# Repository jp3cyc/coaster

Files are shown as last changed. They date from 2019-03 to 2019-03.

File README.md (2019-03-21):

# coaster
光る！コースタです。いざって時(e.g. 友達が遊びに来た、地震、台風の時とか)にはArduinoとしても活躍します。

# 用意するもの
## 部品
- チップLED 1608サイズ 12個
- チップ抵抗 270Ω 1608サイズ 12個
- チップ抵抗 10kΩ 1608サイズ 1個
- ATMEGA328P-AU 1個
- 基板実装型スイッチ 1個
- CR2032表面実装型ケース 1個
- CR2032 1個

## 道具
- AVR書き込み機　または Arduino UNO
- はんだごて
- はんだ
- リフロー炉（あれば楽）
- クリームはんだ（あれば楽）
- ピンセット（あれば便利）
- 顕微鏡（あれば便利）
- レーザ加工機（自宅にあると◎、ない場合はファボラボ or カインズに行く、カッターで頑張るのもあり）

# How to makke
1. プリント基板を注文する。Fusion PCB、PCBgogo、Elecrowとか。10枚$10＋送料です。coaster/circuit/garb/coaster-garbdata.zipを送るだけ
1. プリント基板が届くまでに部品を注文する。http://aki.prioris.jp/list/31d5aa3b-d171-41f0-a121-0a985a356ac1/ ワンクリックですべての部品があきづきカートに入ります。一個分の部品です。
1. コースタ基板を入れるためのケースを作ります。coaster-cutting.aiに入っているデータを誤自宅のレーザカッタで切断します。データはIllustrator形式ですが、みるだけならCoral Drawとかでもいけます。
1. はんだづけします。
1. AVRのFuseビットを変更します。lfuse:0xe2, hfuse:0xde, efuse:0x07（書き込めない場合はY1に8MHzの水晶、C1,C2に22pFのコンデンサをつけてみる）(firwareフォルダにコマンドが入っています）
1. プログラムを書き込みます。coaster-firmware/coaster-firmware.ino.with_bootloader.eightanaloginputs.hexを書き込みます。
1. ボタン電池を入れて、スイッチを入れるとつくはずです。つかなければ、電池残量、スイッチ、はんだ付けを見てみます。

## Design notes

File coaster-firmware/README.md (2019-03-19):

ヒューズ読み出し
avrdude -c usbasp -p m328p -U lfuse:r:con:h -U hfuse:r:con:h -U efuse:r:con:h

ヒューズ書き込み
avrdude -c usbasp -p m328p -U lfuse:w:0xe2:m -U hfuse:w:0xde:m -U efuse:w:0x07:m

bin書き込み
avrdude -c usbasp -p m328p -U flash:w:coaster-firmware.ino.with_bootloader.eightanaloginputs.hex

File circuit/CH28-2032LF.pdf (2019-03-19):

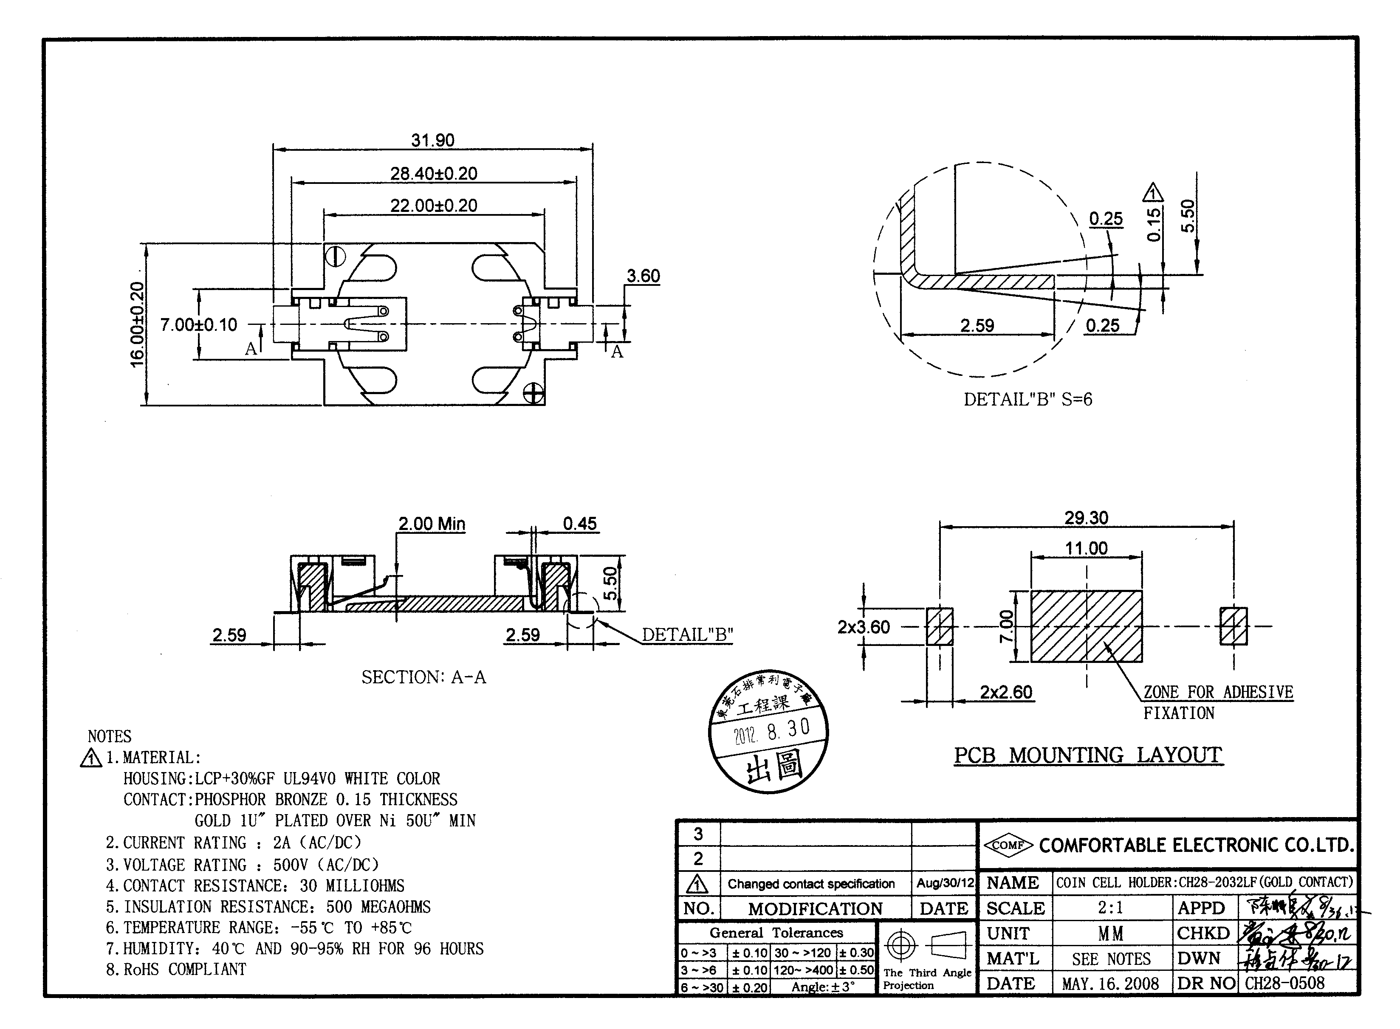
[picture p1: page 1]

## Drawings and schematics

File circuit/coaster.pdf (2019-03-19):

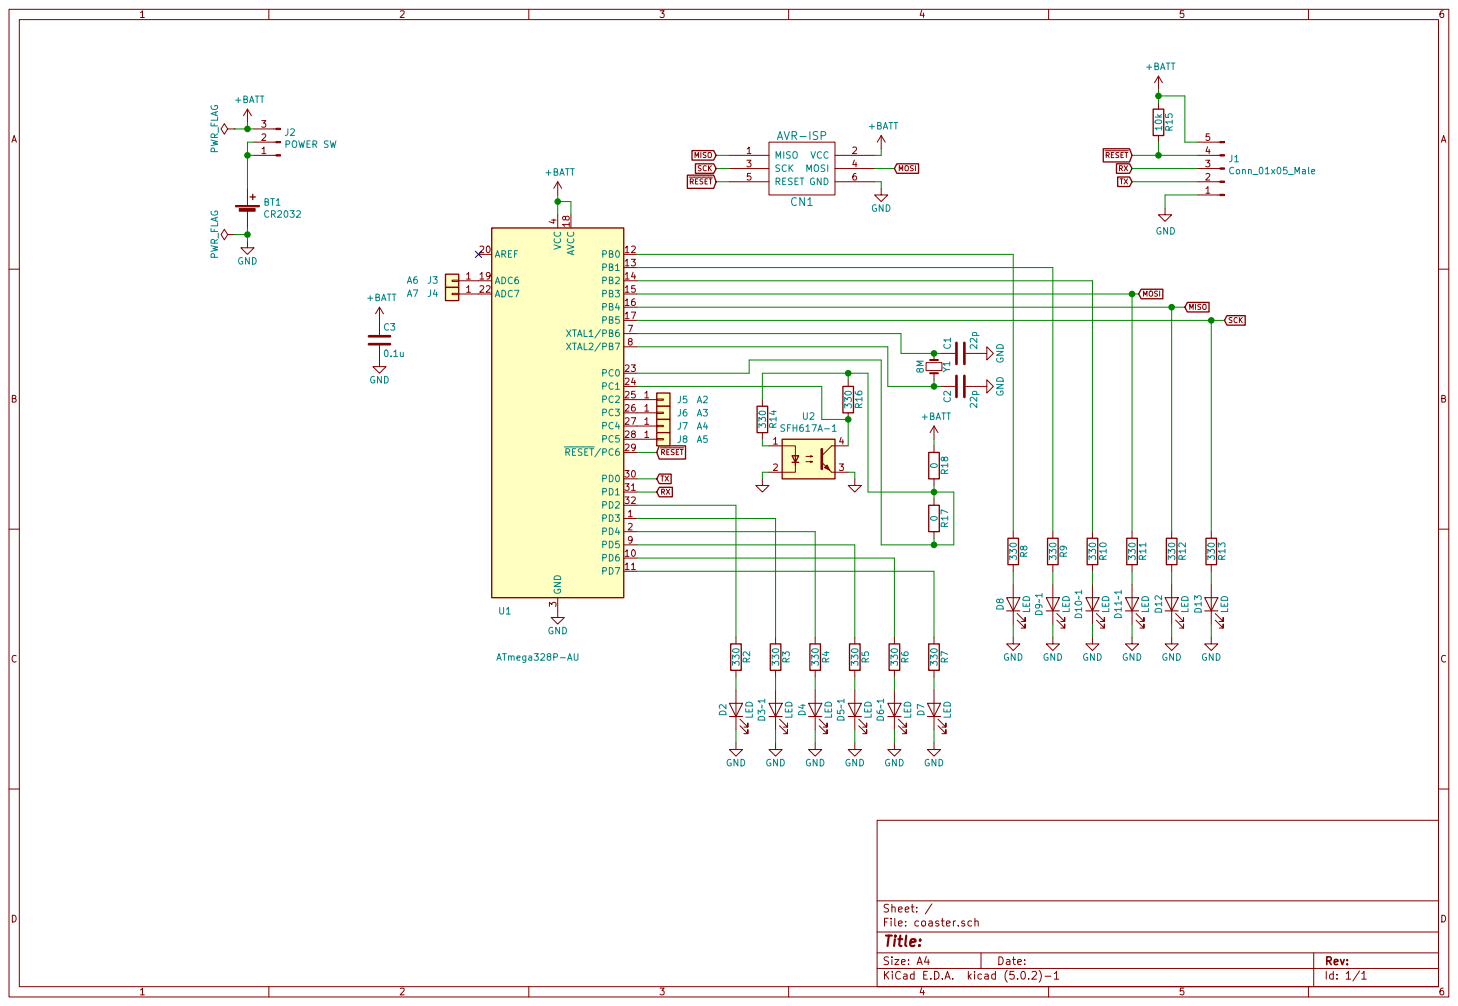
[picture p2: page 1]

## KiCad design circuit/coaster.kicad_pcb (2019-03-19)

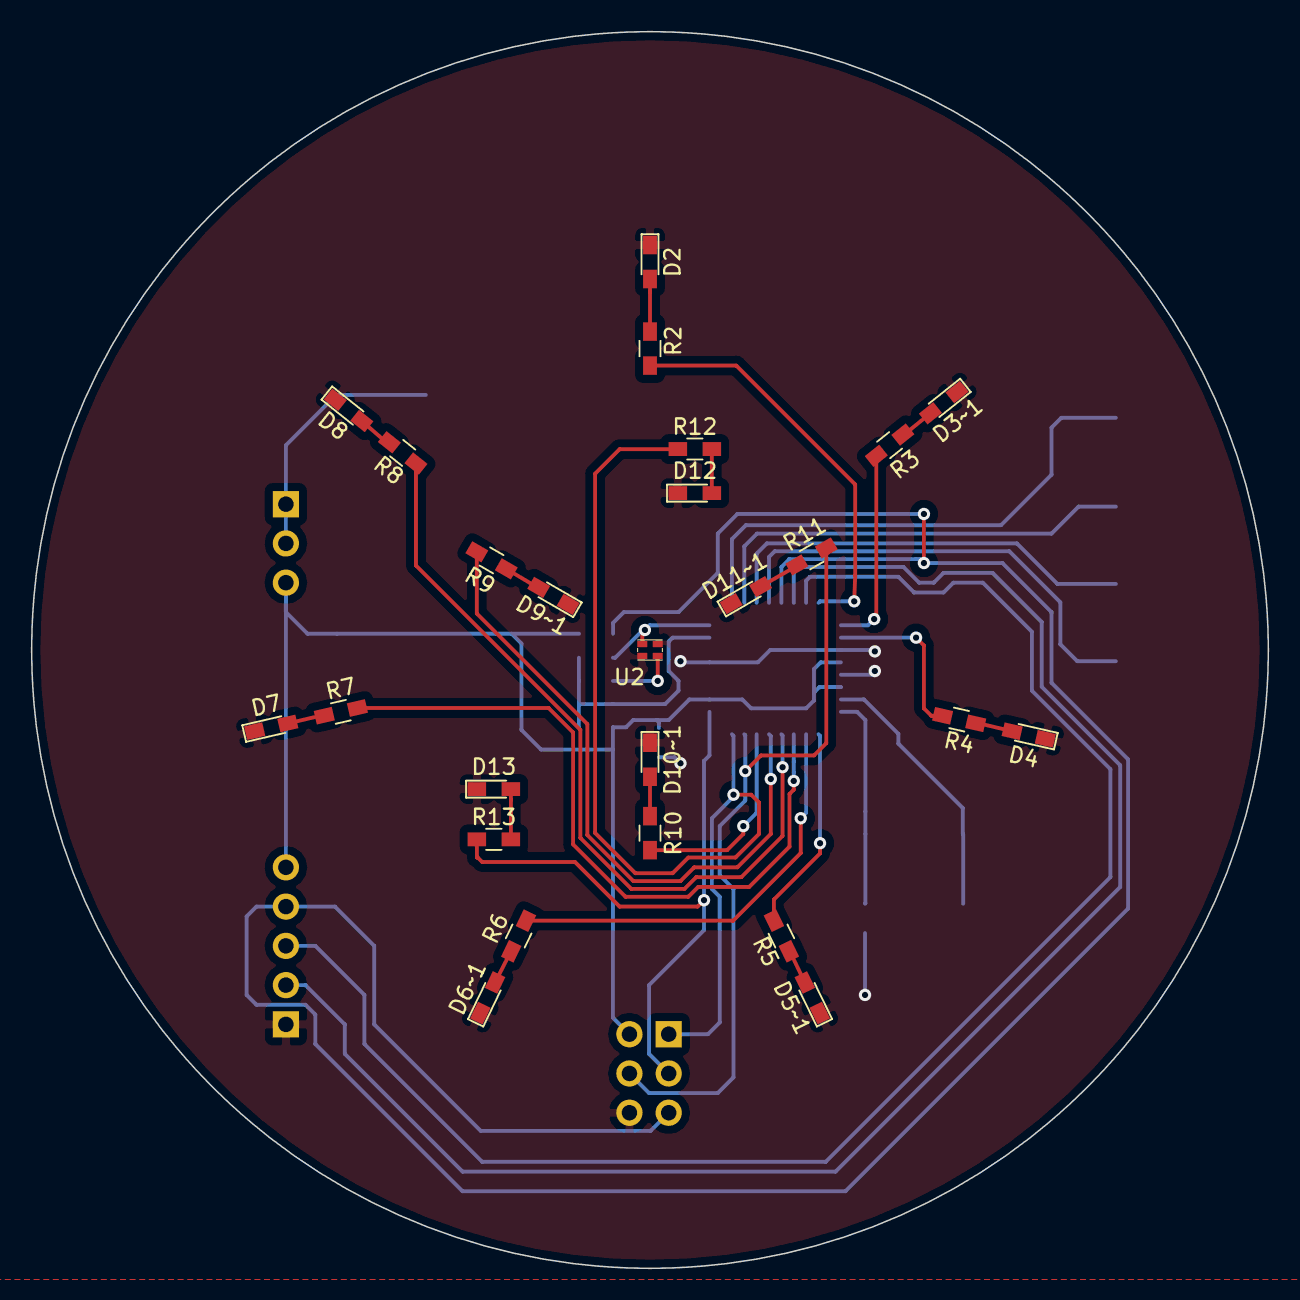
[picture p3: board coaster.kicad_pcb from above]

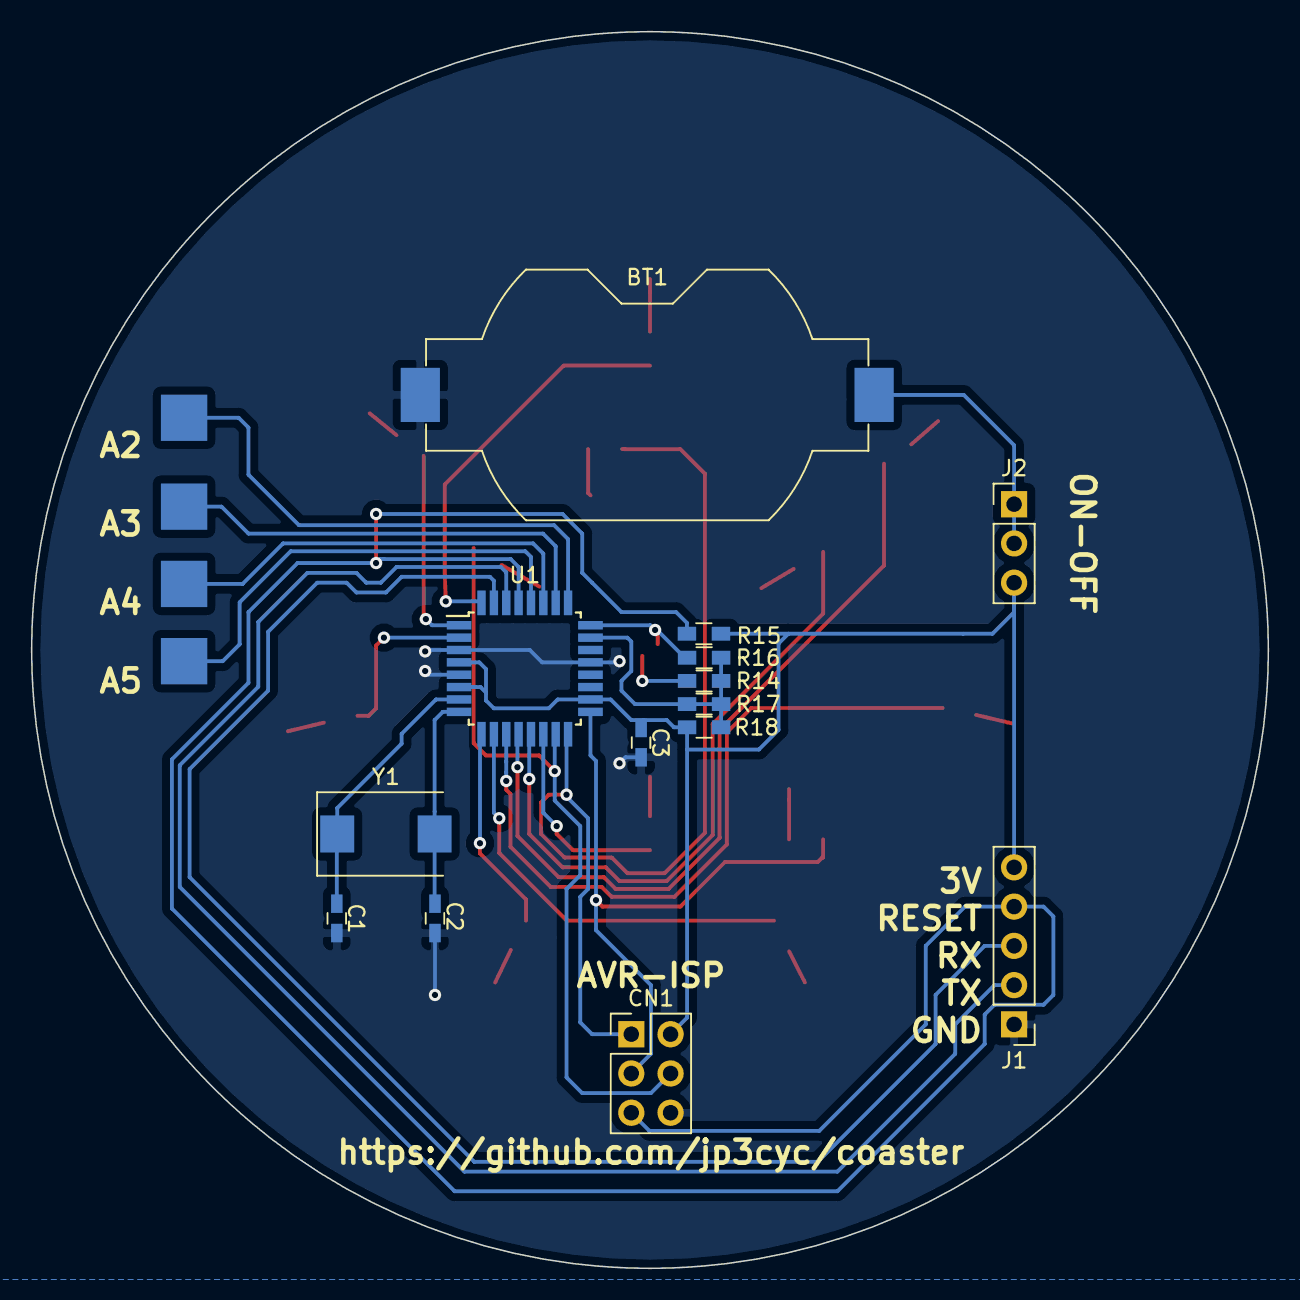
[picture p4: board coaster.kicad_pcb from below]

Board: 2 copper layers, 80.0 x 80.0 mm, 43 parts (18 on the bottom side), 39 nets.

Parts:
BT1: CR2032; Keystone_1058_1x2032-CoinCell
C1, C2: 22p; C_0603_HandSoldering
C3: 0.1u; C_0603_HandSoldering
CN1: AVR-ISP; Pin_Header_Straight_2x03_Pitch2.54mm
D2, D3~~1, D4, D5~~1, D6~~1, D7, D8, D9~~1, D10~~1, D11~~1, D12, D13: LED; LED_0603_HandSoldering
J1: Conn_01x05_Male; Pin_Header_Straight_1x05_Pitch2.54mm
J2: POWER SW; Pin_Header_Straight_1x03_Pitch2.54mm
J5: A2; Measurement_Point_Square-SMD-Pad_Big
J6: A3; Measurement_Point_Square-SMD-Pad_Big
J7: A4; Measurement_Point_Square-SMD-Pad_Big
J8: A5; Measurement_Point_Square-SMD-Pad_Big
R2, R3, R4, R5, R6, R7, R8, R9, R10, R11, R12, R13, R14, R16: 330; R_0603_HandSoldering
R15: 10k; R_0603_HandSoldering
R17, R18: 0; R_0603_HandSoldering
U1: ATmega328P-AU; TQFP-32_7x7mm_Pitch0.8mm
U2: SFH617A-1; NJK5901AR1
Y1: 8M; Crystal_SMD_EuroQuartz_MQ2-2pin_7.0x5.0mm

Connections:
+BATT: C3.1, CN1.2, J1.5, J2.3, R15.1, R18.1, U1.4, U1.6, U1.18
GND: BT1.2, C1.2, C2.2, C3.2, CN1.6, D2.1, D3~~1.1, D4.1, D5~~1.1, D6~~1.1, D7.1, D8.1, D9~~1.1, D10~~1.1, D11~~1.1, D12.1, D13.1, J1.1, U1.3, U1.5, U1.21, U2.2, U2.3
MISO: CN1.1, R12.1, U1.16
MOSI: CN1.4, R11.1, U1.15
unnamed: BT1.1, J2.1, J2.2
unnamed: C1.1, U1.7, Y1.1
unnamed: C2.1, U1.8, Y1.2
unnamed: D2.2, R2.2
unnamed: D3~~1.2, R3.2
unnamed: D4.2, R4.2
unnamed: D5~~1.2, R5.2
unnamed: D6~~1.2, R6.2
unnamed: D7.2, R7.2
unnamed: D8.2, R8.2
unnamed: D9~~1.2, R9.2
unnamed: D10~~1.2, R10.2
unnamed: D11~~1.2, R11.2
unnamed: D12.2, R12.2
unnamed: D13.2, R13.2
unnamed: J5.1, U1.25
unnamed: J6.1, U1.26
unnamed: J7.1, U1.27
unnamed: J8.1, U1.28
unnamed: R2.1, U1.32
unnamed: R3.1, U1.1
unnamed: R4.1, U1.2
unnamed: R5.1, U1.9
unnamed: R6.1, U1.10
unnamed: R7.1, U1.11
unnamed: R8.1, U1.12
unnamed: R9.1, U1.13
unnamed: R10.1, U1.14
unnamed: R14.1, R16.1, R17.1, R17.2, R18.2, U1.23
unnamed: R14.2, U2.1
unnamed: R16.2, U1.24, U2.4
RX: J1.3, U1.31
SCK: CN1.3, R13.1, U1.17
TX: J1.2, U1.30
~RESET: CN1.5, J1.4, R15.2, U1.29

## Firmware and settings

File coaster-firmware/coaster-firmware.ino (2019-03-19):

#define NUM_LED 12

int pin_led[NUM_LED] = {2,3,4,5,6,7,8,9,10,11,12,13};

int cnt = 1;

void setup() {
  // put your setup code here, to run once:
  for(int i=0;i<NUM_LED;i++){
    pinMode(pin_led[i],OUTPUT);
  }
}

void loop() {
  // put your main code here, to run repeatedly:
  if(cnt > 0xfff) cnt = 0;
  led_write(cnt);
  cnt++;
  delay(1000);
}

void led_write(int led_pattern){
  for(int i=0;i<NUM_LED;i++){
    digitalWrite(pin_led[i],(led_pattern>>i)&0x01);
  }
}

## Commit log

2019-03-19 initcommit うごいた
    [coaster-2019-02-13-16-42-46.sch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]
2019-03-19 Fix AVRマイコンの型番
